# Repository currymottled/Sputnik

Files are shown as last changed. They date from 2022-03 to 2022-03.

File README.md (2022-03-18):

# Sputnik
PCB soldering kit themed like Sputnik 1 space probe. Board involves 12 LED's (with pads for SMT and through hole LED's) in a charlieplexed configuration aswell as a double Op-amp (LM358P)speaker circuit integrated into a single circular PCB designed to be house in a transparent 3-d printed shell modeled after the Sputnik 1 space probe. The on-board microcontroller is the ATtiny 202 which is small and cheap aswell as able to be programmed using the UPDI interface and an Arduino as UPDI programmer.
Photo on 2022-03-15 at 9 42 PM

https://user-images.githubusercontent.com/80080396/158929736-c4723393-8633-4ffb-9a50-728e82984238.mov

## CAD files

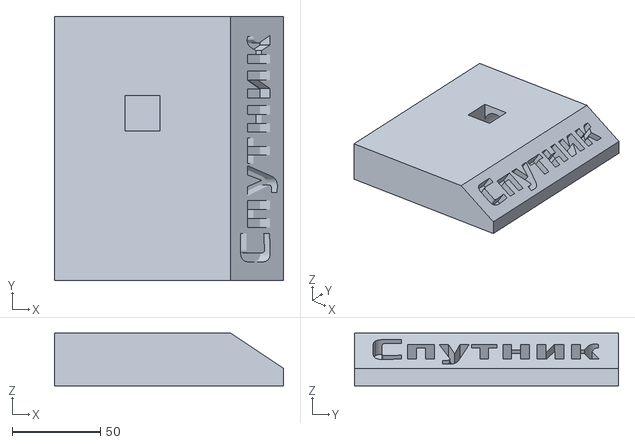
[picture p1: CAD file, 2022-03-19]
Sputnik Stand Base v1.stl
130.0 x 150.0 x 30.0

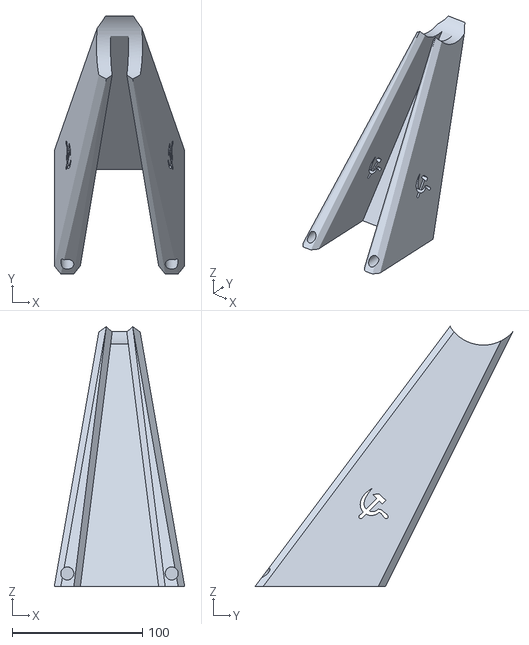
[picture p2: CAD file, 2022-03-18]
Sputnik Satelite holder v1.stl
100.0 x 197.7 x 199.3

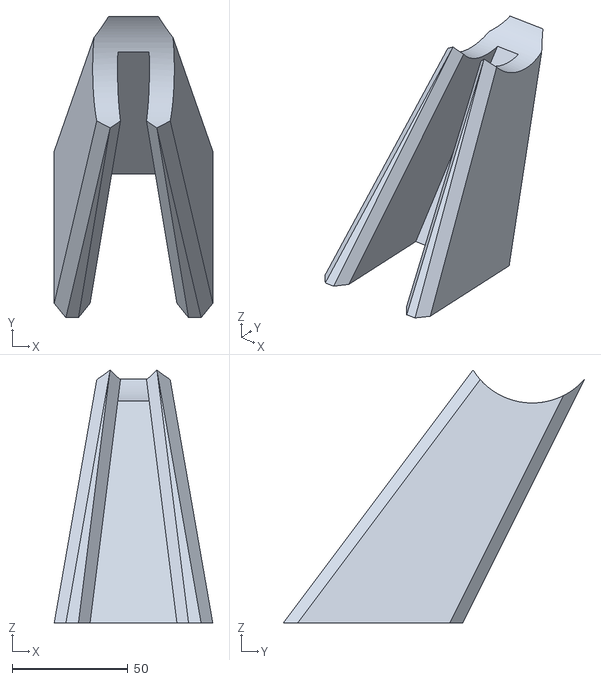
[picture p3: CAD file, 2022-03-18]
Sputnik Satelite Stand Top.stl
68.5 x 130.2 x 109.3

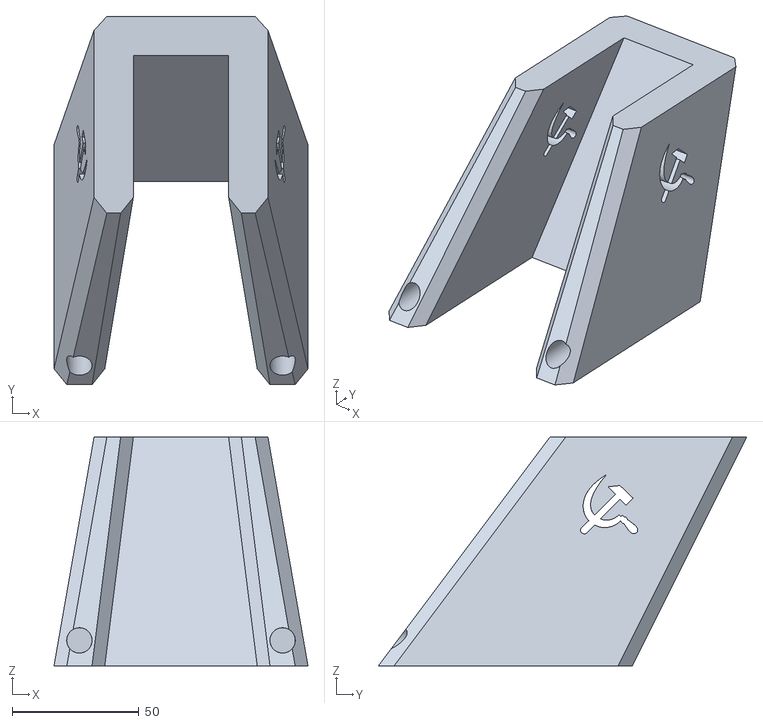
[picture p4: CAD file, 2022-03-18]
Sputnik Satelite Stand Bottom.stl
100.0 x 145.0 x 90.0

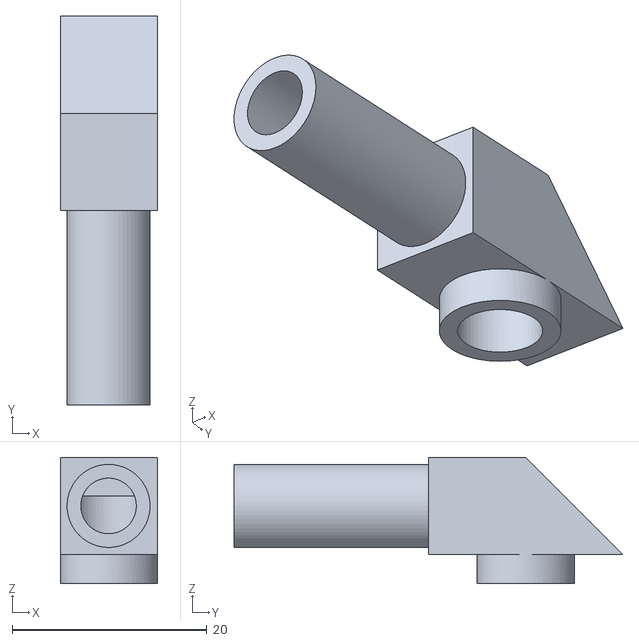
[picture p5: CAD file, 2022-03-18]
Sputnik Arm v1.stl
10.0 x 40.0 x 13.0

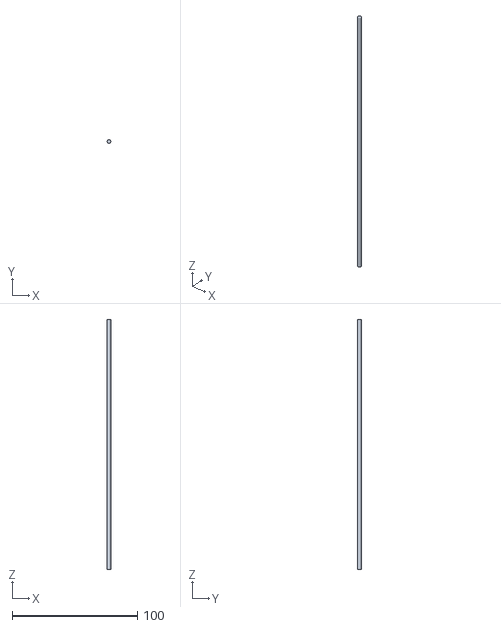
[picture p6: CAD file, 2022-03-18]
Sputnik Legs v1.stl
3.00 x 3.00 x 200.0

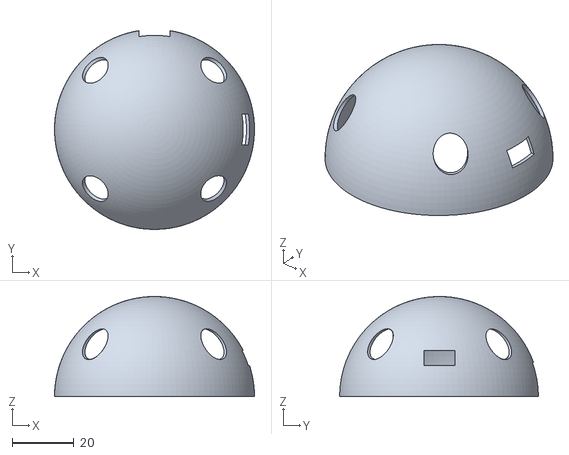
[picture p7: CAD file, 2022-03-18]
Sputnik v1 Top.stl
65.0 x 64.6 x 32.5

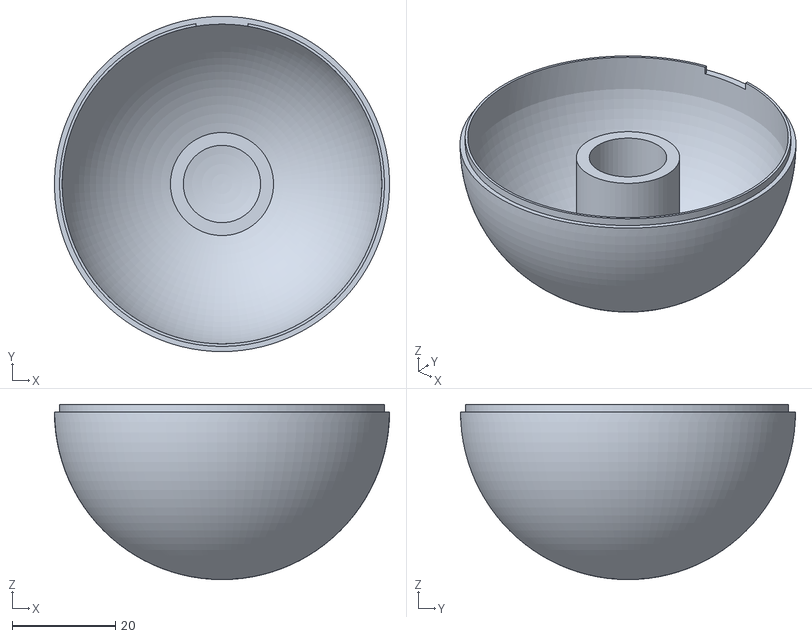
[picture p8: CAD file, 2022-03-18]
Sputnik v1 Bottom.stl
65.0 x 65.0 x 34.0

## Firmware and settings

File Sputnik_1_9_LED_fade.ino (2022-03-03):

//March 2 code developed to use PWM to fade 9 of the 12 LED's which can be controlled via the PWM enabled pins on the ATTiny202 MCU
//Functions are defined that can be called upon to fade desired diodes on the board. 
//Developed as part of the Sputnik 1 project by Lachlan Van Egmond and Maxim Vasic.

int A = 0; //Sets variables equal to the Arduino definition of the ATtiny202 pins.
int B = 1;
int C = 3;
int D = 4;
int Delay =0; //Sets the variable for the delay function so it can be adjusted easier. 
//Please note that the fade functions are slower than a blink (they take 5 miliseconds to max and 5 miliseconds to min) and thus significant delay between functions which are already slow is unadvisable
void setup() //Default pin settings is low impedance OUTPUT mode.
{
  pinMode(A, OUTPUT);
  pinMode(B, OUTPUT); 
  pinMode(C, OUTPUT);
  pinMode(D, OUTPUT); 
}

void setLED(int pinPair) //Defines all the functions that turn on each individual LED. This is done by setting pins as INPUT effectively removing them
//from the circuit due to the high impedance state that an INPUT assignemnt creates
//and then defining the pin pair that will illuminate the desired diode and the polarity of HIGH/LOW for that pair. PLEASE NOTE: Diodes are numbered on the top side (the side with the speaker, MCU, etc.) 
//meaning that value of pinPair is NOT the value of the Diode indicated on the PCB schematic (ex. pinPair 1 turns on Diode 12
{
  if(pinPair == 1) //Turns on Diode 12
  {
                pinMode(A, INPUT);
                pinMode(B, INPUT);  // changed to input to trigger tri state.
                pinMode(C, OUTPUT);
                pinMode(D, OUTPUT);  

                //digitalWrite(D, HIGH); 
                digitalWrite(C, LOW); //Pin C kept low             

  //Fading OUTPUT D using PWM
  for(int i=0; i<255; i++){
    analogWrite(D, i); //Uses analogWrite function for the desired pin increases duty cycle to max
    delay(5);
  }

  for(int i=255; i>0; i--){
    analogWrite(D, i); //Uses analogWrite function for the desired pin decreases duty cycle to min
    delay(5);
  }}
  
  if(pinPair == 2) //Turns on Diode 11
  {
                pinMode(A, INPUT);
                pinMode(B, INPUT); 
                pinMode(C, OUTPUT);
                pinMode(D, OUTPUT);

                //digitalWrite(C, HIGH);             
                digitalWrite(D, LOW); //Pin D kept low

  //Fading the OUTPUT C using PWM
  for(int i=0; i<255; i++){
    analogWrite(C, i);
    delay(5);
  }

  for(int i=255; i>0; i--){
    analogWrite(C, i);
    delay(5);
  }}
  
  if(pinPair == 3) //Turns on Diode 7
  { 
                pinMode(A, OUTPUT);
                pinMode(B, INPUT);
                pinMode(C, OUTPUT);
                pinMode(D, INPUT);

             //digitalWrite(C,HIGH);
                digitalWrite(D, LOW);   

  //Fading OUTPUT C
  for(int i=0; i<255; i++){
    analogWrite(C, i);
    delay(5);
  }

  for(int i=255; i>0; i--){
    analogWrite(C, i);
    delay(5);
  }}
  
  if(pinPair == 4) //Turns on Diode 9 THIS IS NOT A PWM PIN DO NOT CALL THIS FUNCTION FOR PWM PURPOSES. 
  {
                pinMode(A, OUTPUT);
                pinMode(B, INPUT);
                pinMode(C, OUTPUT);
                pinMode(D, INPUT);
                
                digitalWrite(A, HIGH); //Pin 0 does not have PWM capabilities and thus cannot be used
                digitalWrite(C,LOW);
                
  }

  if(pinPair == 5) //Turns on Diode 8
  {
                pinMode(A, INPUT);
                pinMode(B, OUTPUT);
                pinMode(C, INPUT);    
                pinMode(D, OUTPUT);           

                //digitalWrite(D, HIGH);
                digitalWrite(B, LOW);

  //Fading OUTPUT D
  for(int i=0; i<255; i++){
    analogWrite(D, i);
    delay(5);
  }

  for(int i=255; i>0; i--){
    analogWrite(D, i);
    delay(5);
  }}
  
  if(pinPair == 6) //Turns on Diode 10
  {

                pinMode(A, INPUT);
                pinMode(B, OUTPUT);
                pinMode(C, INPUT);
                pinMode(D, OUTPUT);  

                //digitalWrite(B, HIGH);
                digitalWrite(D, LOW);

  //Fading the LED
  for(int i=0; i<255; i++){
    analogWrite(B, i);
    delay(5);
  }

  for(int i=255; i>0; i--){
    analogWrite(B, i);
    delay(5);
  }}
  
    if(pinPair == 7) //Turns on Diode 3 THIS IS NOT A PWM PIN DO NOT CALL THIS FUNCTION FOR PWM PURPOSES
  {

               pinMode(A, OUTPUT);
                pinMode(B, INPUT);
                pinMode(C, INPUT);
                pinMode(D, OUTPUT);  

                digitalWrite(A, HIGH); //Pin 0 on the ATtiny202 does not have PWM functionality
                digitalWrite(D, LOW);
  }
  if(pinPair == 8) //Turns on Diode 2
  {

               pinMode(A, OUTPUT);
                pinMode(B, INPUT);
                pinMode(C, INPUT);
                pinMode(D, OUTPUT);  

                //digitalWrite(D, HIGH);
                digitalWrite(A, LOW);
                
  //Fading the LED
  for(int i=0; i<255; i++){
    analogWrite(D, i);
    delay(5);
  }

  for(int i=255; i>0; i--){
    analogWrite(D, i);
    delay(5);
  }}
  
   if(pinPair == 9) //Turns on Diode 5
  {

               pinMode(A, INPUT);
                pinMode(B, OUTPUT);
                pinMode(C, OUTPUT);
                pinMode(D, INPUT);  

                //digitalWrite(B, HIGH);
                digitalWrite(C, LOW);

  //Fading the LED
  for(int i=0; i<255; i++){
    analogWrite(B, i);
    delay(5);
  }

  for(int i=255; i>0; i--){
    analogWrite(B, i);
    delay(5);
  }}
  
   if(pinPair == 10) //Turns on Diode 6
  {

               pinMode(A, INPUT);
                pinMode(B, OUTPUT);
                pinMode(C, OUTPUT);
                pinMode(D, INPUT);  

                //digitalWrite(C, HIGH);
                digitalWrite(B, LOW);

  //Fading the LED
  for(int i=0; i<255; i++){
    analogWrite(C, i);
    delay(5);
  }

  for(int i=255; i>0; i--){
    analogWrite(C, i);
    delay(5);
  }}
  
   if(pinPair == 11) //Turns on Diode 4
  {

               pinMode(A, OUTPUT);
                pinMode(B, OUTPUT);
                pinMode(C, INPUT);
                pinMode(D, INPUT);  

                //digitalWrite(B, HIGH);
                digitalWrite(A, LOW);

  //Fading the LED
  for(int i=0; i<255; i++){
    analogWrite(B, i);
    delay(5);
  }

  for(int i=255; i>0; i--){
    analogWrite(B, i);
    delay(5);
  }}
  
   if(pinPair == 12) //Turns on Diode 1 THIS IS NOT A PWM PIN DO NOT CALL THIS FUNCTION FOR PWM PURPOSES
  {

               pinMode(A, OUTPUT);
                pinMode(B, OUTPUT);
                pinMode(C, INPUT);
                pinMode(D, INPUT);  

                digitalWrite(A, HIGH); //Pin 0 on the ATtiny202 does not have PWM
                digitalWrite(B, LOW);
                
  }
  }

void loop() //Cycles through the desired sequence of the above sequences of pin definitions and HIGH/LOW settings
{
  {
    setLED(1);
    delay(Delay);
    setLED(2);
    delay(Delay);
    setLED(3);
    delay(Delay);
    //setLED(4); Function commmented out due to hardware inability to use PWM
    //delay(Delay);
    setLED(5);
    delay(Delay);
    setLED(6);
    delay(Delay);
    //setLED(7); Function commented out due to hardware inability to use PWM
    //delay(Delay);
    setLED(8);
    delay(Delay);
    setLED(9);
    delay(Delay);
    setLED(10);
    delay(Delay);
    setLED(11);
    delay(Delay);
    //setLED(12); Function commented out due to hardware inability to use PWM
    //delay(Delay);
  }
}

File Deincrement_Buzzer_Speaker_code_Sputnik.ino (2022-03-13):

//By Lachlan Van Egmond
int buzzerPin = 4; //Which is the pin on the Attiny202 that controls the buzzer and at this point some of the lights (which will be fixed in version 2.0 of the Sputnik)

int buzzerPitch = 3000; //value of the pitch for the tone function during deincrement beeps

void setup() {

tone(buzzerPin, buzzerPitch ); //time incremented 
  delay(1000);
  noTone(buzzerPin);
  delay(1000);
  tone(buzzerPin, buzzerPitch );
  delay(900);
  noTone(buzzerPin);
  delay(900);
  tone(buzzerPin, buzzerPitch );
  delay(800);
  noTone(buzzerPin);
  delay(800);
  tone(buzzerPin, buzzerPitch );
  delay(700);
  noTone(buzzerPin);
  delay(700);
  tone(buzzerPin, buzzerPitch );
  delay(600);
  noTone(buzzerPin);
  delay(600);
  tone(buzzerPin, buzzerPitch );
  delay(500);
  noTone(buzzerPin);
  delay(500);
  tone(buzzerPin, buzzerPitch );
  delay(400);
  noTone(buzzerPin);
  delay(400);
  tone(buzzerPin, buzzerPitch );
  delay(300);
  noTone(buzzerPin);
  delay(300);
  tone(buzzerPin, buzzerPitch );
  delay(200);
  noTone(buzzerPin);
  delay(200);
  tone(buzzerPin, buzzerPitch );
  delay(100);
  noTone(buzzerPin);
  delay(100);
  tone(buzzerPin, buzzerPitch );
  delay(50);
  noTone(buzzerPin);
  delay(50);
  tone(buzzerPin, buzzerPitch );
  delay(25);
  noTone(buzzerPin);
  delay(25);
  tone(buzzerPin, buzzerPitch );
  delay(10);
  noTone(buzzerPin);
  delay(10);
  tone(buzzerPin, buzzerPitch );
  delay(5);
  noTone(buzzerPin);
  delay(5);
  tone(buzzerPin, buzzerPitch );
  delay(2.5);
  noTone(buzzerPin);
  delay(2.5);
  tone(buzzerPin, buzzerPitch );
  delay(1);
//  noTone(buzzerPin, buzzerPitch);
  //delay(1);


}

void loop() {

  tone(buzzerPin, 3500 ); // end frequency
  delay(6000);

 }

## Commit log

2022-03-01 Add files via upload
    First code run on the Sputnik 1 board (first board design manufactured)
2022-03-01 Blink each LED in top and bottom circular sequence
    Blinks the top and bottom LED's in sequence at an interval of 200 milliseconds.
2022-03-01 Top of board LED's circle blink
    Cycles through Diodes 12,11,7,9,8,10 with 50 milliseconds between each blink. This forms a circular pattern on the top side of the board only.
2022-03-03 Initial 9 LED fade program test
    Experimented with the PWM functions on the various pins of the ATtiny202 although not all pins are PWM enabled. Potential possibility to enable all 12 LED's with PWM function in the future by switchi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
2022-03-18 Bottom of version 1 3-d printed case
    [Sputnik v1 Bottom.stl]
2022-03-18 Top of version 1 3-d printed case
    [Sputnik v1 Top.stl]
2022-03-18 Legs of version 1 3-d printed case
    Due to the fibre optics that illuminate the ends not be rigid enough to hold themselves erect as the original legs of the sputnik were 3 mm in diameter by 200mm long rods needed to be printed to supp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
    [Sputnik Legs v1.stl]
2022-03-18 Arm's (connectors to the legs and top) for 3-D
    Arm of the sputnik which are hollow to allow passage of the fibre optic and of course the iconic legs of the probe.
    [Sputnik Arm v1.stl]
2022-03-18 Most recent updated schematic
    Changes have been made to ensure that pin 7 on the ATtiny202 does NOT run both the speaker circuit and as an I/O for the LED charlieplexing because during round one tests this resulted in a ticking noise if simple on off code was run (as would be expected if you hooked up digital pins to a speaker and toggled them) Pin 4 was PWM enabled and free so the decision was made to run the speaker off that pin instead of pin 7 to avoid unwanted interference.
2022-03-18 Sputnik V2 Board (second revision)
    Second revision of the Sputnik project board:
    Changes implemented:
    1) ATtiny202 pin 7 is no longer being used as an I/O for the LED configuration AND as the speaker signal instead pin 7 is now exclusively I/O and pin 4 exclusively runs the speaker circuit
    2) Spacing around the power jack of D3 (diode 3) has been increased so that regardless of whether through hole or SMT components are used soldering is easy.
    3) The pull up resistor on the UPDI pin now has the potential to be soldered in initially and activated later after programming by either soldering in a switch and closing that circuit or by creating a solder bridge between the added pads.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
2022-03-18 Satellite Stand Bottom 3-d file
    A soviet themed stand was created for those wishing to put the Sputnik on their desk as and accessory this is the bottom of that stand
    [Sputnik Satelite Stand Bottom.stl]
2022-03-18 Sputnik Satellite Stand Top
    A soviet themed stand was created for those wishing to put the Sputnik on their desk as and accessory this is the top of that stand. It is printed in two separate pieces (at least on the Ender 3) and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
    [Sputnik Satelite Stand Top.stl]
2022-03-18 Entire Sputnik Stand file
    This is the combined file of both halves as one for those with a large 3-D printer at their disposal.
    [Sputnik Satelite holder v1.stl]
2022-03-18 Second version of the schematic with a bus
    Second version of the schematic with a bus used instead of individual wires to clean it up
2022-03-19 Base for the sputnik stand
    Currently untested because it requires 100% infilled
    [Sputnik Stand Base v1.stl]
2022-03-19 Sputnik PBC V2.1
    Version two board with the updated speaker and power jack patterns. Currently the final iteration of the Sputnik 1 satellite PCB.
2022-03-19 Sputnik 2.2
    Most recent iteration of PCB. Changes from 2.1 are connection of power jack VCC directly to VCC line rather than pull up resistor and switch.
2022-03-19 Sputnik PCB Version 2.3
    This is the final V2 file that will be put into production for the second design revision.
